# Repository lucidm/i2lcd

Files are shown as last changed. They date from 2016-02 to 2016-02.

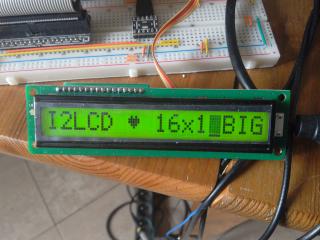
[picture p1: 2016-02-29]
pictures/16x1-big.jpg

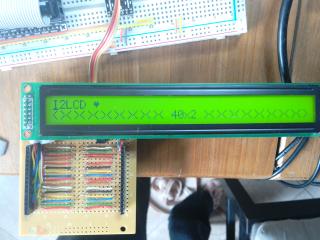
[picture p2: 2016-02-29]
pictures/40x2.jpg

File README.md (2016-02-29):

## I2LCD - I2C HD4470 expansion board with software controlled contrast and backlight

Here's little project of electronic module for ubiquitous Hitachi HD4470 based
alphanumeric displays. Main reason for making the project was to drive the
display using I2C bus. There are many existing I2C extension boards, with most popular
built upon NXP PCF8574 8 bit port expander. This module however, use NXP PCA9535 16 bit expander and
provide few additional functions.

PCB of the module was made in KiCAD 4.0. Generated gerber
files were sent to the PCD manufacturer and after few minor modifications and
few weeks later, PCB of a prototype were sent back. Here are the results.

## What's the difference.

- **Full 8 bit communication with the display**.
  It uses PCA9535 16 bit expander, so we have spare IO ports to
communicate using full 8 bit width words. In popular I2C expansion modules
4 bits are used to drive control lines of the display and 4 other bits are used
as data lines. This module project, was made to provide full 8 bit communication.
No need to send data bytes as two 4 bit chunks although sent as 8 bits of which
4 bits are meaningful and 4 other are just ignored.

- **You can read data from the display**.
  Not all I2C modules provide ability to read from the display. Some of
implementations have hard-wired R/W line assuming user will always write to the
display. Using this module you are able to read data from the module. Attached example
libraries use this feature to read the busy flag of the display. No longer
arbitrary delays in your code, your code waits as long as it is required for the
display to finish.

- **Contrast and backlight intensity are handled programmatically**.
  Another eight IO lines are used for driving control lines of a display and
changing backlight intensity, setting contrast and other functions.
Usually I2C expansion modules use a potentiometer to set contrast of a
display, depending on the module, contrast setting may differ, so you take
a screwdriver and change the pot until the display shows its content with
desired contrast. The module has two electronic potentiometers to set
the contrast and for changing backlight intensity. Where on popular I2C
modules you're able to switch backlight on or off. Potentiometers use simple
Up/Down communication protocol.

- **You can programmatically switch on or off the display power supply**.
Additional line is used to switch the display power on or off. If for some reason
the display should be switched off (to save battery usage for example), you can
do it from your code. However there are some issues regarding this version of
module. Read this Wiki article about known issues and how to get rid of them.

If you like to read more about the module please follow this link:
https://github.com/lucidm/i2lcd/wiki

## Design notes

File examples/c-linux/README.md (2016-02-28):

## I2LCD Userspace C library

Here is I2LCD library written in C for Linux. Library use exsiting I2C device
so the modules for I2C bus should be loaded into kernel prior to use this library.
No external libraries were linked, library use Linux API entirely.

Main directory contains few examples, i2lcd subdirectory contains source code of
the library.

## Examples:

* editlcd - LCD content editor. You can edit content of the display in realtime in
  convenient window. Editor also allow to edit graphical characters and save its
  definiton to C header file.

* lcdbricontest - simple test using brighness and contrast manipulation which shows
  current value of those parameters on the display.

* lcdtest - simple test of the display

## Library - i2lcd subdirectory

* i2lcd.c - main library source file
* i2lcd.h - header for i2lcd.c
* pca9535.c - source of api for PCA9535 chip used by i2lcd.c
* pca9535.h - header file for the above
* pots.c - source of api of the potentiometers used in the module
* pots.h - header for pots.c api

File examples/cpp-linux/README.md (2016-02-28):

## I2LCD Userspace C++ library

Library for I2LCD module written in C++ for Linux. Library use exsiting I2C device
so the modules for I2C bus should be loaded into the kernel prior to use this library.
No external libraries were linked, library use Linux API entirely. Library defines
I2Lcd class with api methods to control the display. Whole definition was i2lcd
namespace enclosed. Only the '<<' operator is defined outside of the namespace,
to provide ability to dump content of the display to ostream object.

Main directory contains few examples and library itself.

## Examples:

* lcdtest - simple test of the display

## The library

* i2lcd.cpp - main library source file, with I2Lcd class API for the display
* i2lcd.h - header for i2lcd.c
* pca9535.cpp - source of PCA9535 class with its API
* pca9535.h - header file for the above
* pots.cpp - source of Potentiometer class and its API
* pots.h - header for pots.cpp api

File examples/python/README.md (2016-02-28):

## I2LCD Userspace Python library

Here is I2LCD library written in Pyhton for Linux. Library is using exsiting I2C device
so the modules for I2C bus should be loaded into kernel prior to use this library.
No external libraries were used, library use Linux API entirely.

Main directory contains few examples, i2lcd subdirectory contains source code of
the library.

## Examples:

* lcdtest - simple test of the display

## Library - i2lcd subdirectory

* i2lcd.py - main library source file
* lcdconst.py - constants used by the library
* pca9535.py - source of api for PCA9535 chip used by i2lcd.py
* pots.py - source of api of the potentiometers used in the module
* lcdstatusflag.py - classes for different method of maintaining status flags
  of the display

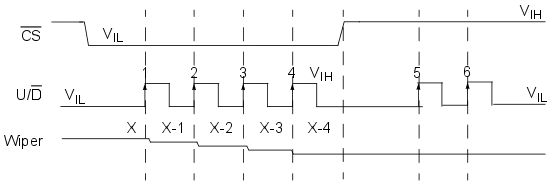
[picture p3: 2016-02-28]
pictures/mcp401x-8.png

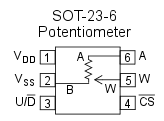
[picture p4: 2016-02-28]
pictures/mcp401x-1.png

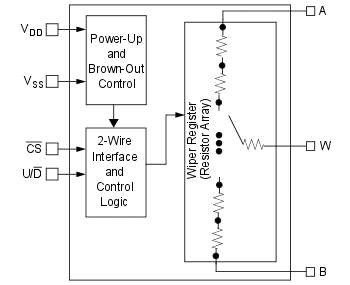
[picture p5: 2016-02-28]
pictures/mcp401x-2.png

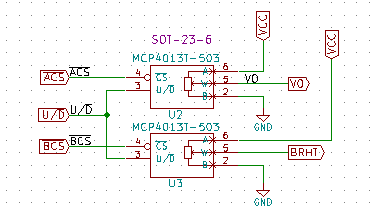
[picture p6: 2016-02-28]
pictures/mcp-connections3.png

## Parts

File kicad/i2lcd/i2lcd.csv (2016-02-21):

Id | Oznaczenie | Obudowa | Ilość | Oznaczenie | Dostawca i numer artykułu
1 | C48,C47,C46,C45,C44,C43,C42,C41,C40,C39,C38,C37,C36,C35,C34,C33,C32,C31,C30,C29,C28,C27,C26,C25,C24,C23,C22,C21,C20,C19,C18,C17,C16,C15,C14,C13,C12,C11,C10,C9,C8,C7,C6,C5,C1,C2,C3,C4 | C_0603 | 48 | 100n
2 | DS12,DS11,DS10,DS9,DS8,DS7,DS6,DS5,DS4,DS3,DS2,DS1 | Pin_Header_Straight_1x16 | 12 | LCD-016N002L
3 | U72,U71,U70,U69,U68,U67,U66,U65,U64,U63,U62,U3 | SOT-23-6 | 12 | MCP4013T-503
4 | U61,U60,U59,U58,U57,U56,U55,U54,U53,U52,U51,U2 | SOT-23-6 | 12 | MCP4013T-503
5 | U50,U49,U48,U47,U46,U45,U44,U43,U42,U41,U40,U39,U38,U37,U36,U35,U34,U33,U32,U31,U30,U29,U5,U4 | SOT-23-5 | 24 | 74AHC1G14
6 | R84,R83,R82,R81,R80,R79,R78,R77,R76,R75,R74,R2 | R_0603 | 12 | 100k
7 | Q24,Q23,Q22,Q21,Q20,Q19,Q18,Q17,Q16,Q15,Q14,Q1 | SOT-23 | 12 | IRLML6244
8 | R73,R72,R71,R70,R69,R68,R67,R66,R65,R64,R63,R4 | R_0603 | 12 | 220k
9 | R62,R61,R60,R59,R58,R57,R56,R55,R54,R53,R52,R40,R39,R38,R37,R36,R35,R34,R33,R32,R31,R30,R29,R28,R27,R26,R25,R24,R23,R22,R21,R20,R19,R18,R17,R16,R15,R14,R13,R12,R11,R10,R9,R8,R3,R5,R6,R7 | R_0603 | 48 | 4.7k
10 | R51,R50,R49,R48,R47,R46,R45,R44,R43,R42,R41,R1 | R_0603 | 12 | 47k
11 | U28,U27,U26,U25,U24,U23,U22,U21,U20,U19,U18,U6 | TSSOP-14_4.4x5mm_Pitch0.65mm | 12 | 74LS21
12 | U17,U16,U15,U14,U13,U12,U11,U10,U9,U8,U7,U1 | TSSOP-24_4.4x7.8mm_Pitch0.65mm | 12 | PCA9535
13 | P24,P23,P22,P21,P20,P19,P18,P17,P16,P15,P14,P1 | Pin_Header_Straight_1x05 | 12 | CONN_01X05
14 | Q13,Q12,Q11,Q10,Q9,Q8,Q7,Q6,Q5,Q4,Q3,Q2 | SOT-23 | 12 | BT2N2222
15 | P13,P12,P11,P10,P9,P8,P7,P6,P5,P4,P3,P2 | SOT-23-6 | 12 | CONN_02X03

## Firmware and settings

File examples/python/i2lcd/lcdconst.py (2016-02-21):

# -*- coding: utf-8 -*-

#Control/Data ports numbers
CPORT = 0
DPORT = 1

#Control port bits meaning
EN = 1
RW = 1 << 1
RS = 1 << 2
IRS = 1 << 3
PWR = 1 << 4
UD = 1 << 5
CCS = 1 << 6
BCS = 1 << 7

#HD4470 instructions
CLEAR_DISPLAY = 1
CURSOR_HOME = 1 << 1
ENTRY_MODE_SET = 1 << 2
DISPLAY_ONOFF = 1 << 3
CURSOR_DISPLAY_SHIFT = 1 << 4
FUNCTION_SET = 1 << 5
SET_CGRAM_ADDRESS = 1 << 6
SET_DDRAM_ADDRESS = 1 << 7

#Values of instructions above
#ENTRY MODE SET
EMS_S = 1		#1 - Shift display
EMS_ID = 1 << 1	#0 - Dec cursor, 1 - inc cursor pos
    
#DISPLAY ON OFF
DOO_B = 1		#1 - Blink ON, 0 - Blink OFF
DOO_C = 1 << 1	#1 - Cursor ON, 0 - Cursor OFF
DOO_D = 1 << 2	#1 - Display ON, 0 - Display OFF
    
    #CURSOR DISPLAY SHIFT
CDS_RL = 1 << 2	#1 - shift right, 0 - shift left
CDS_SC = 1 << 3	#1 - shift display, 0 - move cursor

#FUNCTION SET
FS_F = 1 << 2	#1 - 5x10 dots, 0 - 5x8 dots
FS_N = 1 << 3	#1 - 2 lines, 0 - 1 line
FS_DL = 1 << 4	#1 - 8 bit interface, 0 - 4 bit interface

#BUSY FLAG
BF = 1 << 7		#1 - busy, 0 - can accept instruction

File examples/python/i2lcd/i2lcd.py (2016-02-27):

# -*- coding: utf-8 -*-

from time import sleep
import textwrap
import lcdconst
from pca9535 import PCA9535
from pots import Potentiometer
from statusflag import DelayWaiter, BusyLoop

def _checkPos(function):
    def _f(*args):
	obj = args[0]
	if args[1] >= obj.cols or args[1] < 0:
	    raise ValueError('Column {0} is not between 0-{0}.'.format(args[1], obj.cols - 1))

	if args[2] >= obj.rows or args[2] < 0:
	    raise ValueError('Row {0} is not between 0-{0}.'.format(args[2], obj.rows - 1))

	return function(*args)
    return _f



class I2LCD(object):
    memaddr = {	6  : {1: [0x00], },
                8  : {1: [0x00], 2: [0x40]},
		12 : {4: [0x00, 0x40, 0x0C, 0x4C]},
		16 : {0: [0x00], 1 : [0x00, 0x40], 2 : [0x00, 0x40], 4 : [0x00, 0x40, 0x10, 0x50]},
	        20 : {2 : [0x00, 0x40], 4 : [0x00, 0x40, 0x14, 0x54]},
		24 : {2 : [0x00, 0x40]},
		40 : {2 : [0x00, 0x40]},
	      }

    pottransctable = [0,10,16,21,24,27,29,31,33,35,36,37,39,40,41,42,43,44,44,45,46,47,47,48,49,49,50,50,51,51,52,52,53,53,54,54,55,55,55,56,56,57,57,57,58,58,58,59,59,59,60,60,60,60,61,61,61,62,62,62,62,63,63,63]
    pottransbtable = [0,13,21,27,30,34,36,38,40,42,43,45,46,47,48,48,49,50,51,51,52,52,53,53,54,54,55,55,55,56,56,56,56,57,57,57,58,58,58,58,58,59,59,59,59,59,59,60,60,60,60,60,60,60,60,61,61,61,61,61,61,61,61,61]

    def __init__(self, bus, address, cols, rows):
	self.iface = PCA9535(bus, address)

	if not self.memaddr.has_key(cols):
	    raise NotImplementedError
	if not self.memaddr[cols].has_key(rows):
	    raise NotImplementedError

	self.rowsaddress = self.memaddr[cols][rows]
	self.cols = 8 if rows == 1 else cols
	self.rows = 2 if rows == 1 else rows if rows else 1
	self.column = 0
	self.row = 0
	self.control = 0x00
	self.setControl(self.control, 0)
	self.iface.setPortDir(lcdconst.CPORT, lcdconst.IRS | lcdconst.UD | lcdconst.BCS | lcdconst.CCS)
	self.iface.setPortDir(lcdconst.DPORT, 0x00)
	self.wait = DelayWaiter(self)
	self.iface.setPortOutput(lcdconst.DPORT, 0x00)

	self.cpot = Potentiometer(self.iface, lcdconst.CCS, lcdconst.UD)
	self.bpot = Potentiometer(self.iface, lcdconst.BCS, lcdconst.UD)

	self.control |= self.iface.getPortOutput(lcdconst.CPORT)
	self.setControl(self.control, 1)
	self.commands = {lcdconst.CLEAR_DISPLAY : 0,
			    lcdconst.CURSOR_HOME : 0,
			    lcdconst.ENTRY_MODE_SET : 0,
			    lcdconst.DISPLAY_ONOFF : 0,
			    lcdconst.CURSOR_DISPLAY_SHIFT : 0,
			    lcdconst.FUNCTION_SET : 0,
			    lcdconst.SET_CGRAM_ADDRESS : 0,
			    lcdconst.SET_DDRAM_ADDRESS : 0}
	self.waitflag = 0

    def __del__(self):
	self.power(0)
	self.close()

    def close(self):
	self.setContrast(0x00)
	self.setBacklight(0x00)
	self.setControl(lcdconst.EN | lcdconst.PWR, 0)
	self.iface.setPortDir(lcdconst.CPORT, 0xFF)
	self.iface.setPortDir(lcdconst.DPORT, 0xFF)

    def setControl(self, control, value):
	self.control = (self.control | control) if value else (self.control & ~control)
	self.iface.setPortOutput(lcdconst.CPORT, self.control)

    def setDirection(self, direction):
	self.iface.setPortDir(lcdconst.DPORT, direction)

    def command(self, command, value):
	while (self.waitflag and self.readStatus()[0]):
	    continue
	data = command | value
	self.setControl(lcdconst.RS | lcdconst.RW, 0)
	self.setControl(lcdconst.EN, 1)
	self.iface.setPortOutput(lcdconst.DPORT, data)
	self.setControl(lcdconst.RS | lcdconst.RW | lcdconst.EN, 0)
	self.commands[command] = value

    def readStatus(self):
	self.setControl(lcdconst.RS, 0)
	self.setControl(lcdconst.RW, 1)
	self.setDirection(0xFF)
	self.setControl(lcdconst.EN, 1)
	ret = self.iface.getPortInput(lcdconst.DPORT)
	self.setControl(lcdconst.RS | lcdconst.RW | lcdconst.EN, 0)
	self.setDirection(0x00)
	return (ret & lcdconst.BF, ret & ~lcdconst.BF)

    def writeByte(self, value):
	self.setControl(lcdconst.RS, 1)
	self.setControl(lcdconst.RW, 0)
	self.setControl(lcdconst.EN, 1)
	self.iface.setPortOutput(lcdconst.DPORT, value)
	self.setControl(lcdconst.RS | lcdconst.RW | lcdconst.EN, 0)

    def readBlock(self, l):
	self.setControl(lcdconst.RS, 1)
	self.setControl(lcdconst.RW, 1)
	ret = []
	for b in xrange(l):
	    self.setControl(lcdconst.EN, 1)
	    ret.append(self.iface.getPortInput(lcdconst.DPORT))
	    self.setControl(lcdconst.EN, 0)
	self.setControl(lcdconst.RS | lcdconst.RW | lcdconst.EN, 0)
	return ret

    def writeBlock(self, values):
	self.setControl(lcdconst.RS, 1)
	self.setControl(lcdconst.RW, 0)
	for b in values:
	    self.setControl(lcdconst.EN, 1)
	    self.iface.setPortOutput(lcdconst.DPORT, b)
	    self.setControl(lcdconst.EN, 0)
	self.setControl(lcdconst.RS | lcdconst.RW | lcdconst.EN, 0)

    def readDataByte(self):
	self.setControl(lcdconst.RS, 1)
	self.setControl(lcdconst.RW, 1)
	self.setDirection(0xFF)
	self.setControl(lcdconst.EN, 1)
	ret = self.iface.getPortInput(lcdconst.DPORT)
	self.setControl(lcdconst.RS | lcdconst.RW | lcdconst.EN, 0)
	self.setDirection(0x00)
	return ret

    def readRow(self, row):
	self.command(lcdconst.SET_DDRAM_ADDRESS, self.rowsaddress[row])
	self.setControl(lcdconst.RS, 1)
	self.setControl(lcdconst.RW, 1)
	self.setDirection(0xFF)
	ret = ""
	for i in range(self.cols):
	    self.setControl(lcdconst.EN, 1)
	    ret += chr(self.iface.getPortInput(lcdconst.DPORT))
	    self.setControl(lcdconst.EN, 0)
	self.setControl(lcdconst.RS | lcdconst.RW, 0)
	self.setDirection(0x00)
	self.setCursor(self.column, self.row)
	return ret

    @_checkPos
    def setCursor(self, column, row):
	row %= self.rows
	column %= self.cols
	self.column = column
	self.row = row
	address = self.rowsaddress[row]+column
	self.command(lcdconst.SET_DDRAM_ADDRESS, address)

    def clear(self):
	self.command(lcdconst.CLEAR_DISPLAY, 0x00)
	self.column = 0
	self.row = 0

    def home(self):
	self.command(lcdconst.CURSOR_HOME, 0x00)
	self.column = 0
	self.row = 0

    def setGC(self, number, definition):
	self.command(lcdconst.SET_CGRAM_ADDRESS, ((number & 0x07) << 3))
	self.writeBlock(definition)

    def fprint(self, string):
	column = self.column
	row = self.row

	for i, line in enumerate(string.rstrip().split('\n')):
	    self.command(lcdconst.SET_DDRAM_ADDRESS, self.rowsaddress[row]+column)
	    wrap = textwrap.wrap(line, self.cols if column == 0 else self.cols - column)
	    for j, txt in enumerate(wrap):
		self.writeBlock([ord(c) for c in txt])
		column += len(txt)
		if column >= self.cols:
		    column = 0
		    row = (row + 1) % self.rows
		    self.command(lcdconst.SET_DDRAM_ADDRESS, self.rowsaddress[row]+column)
	    if i > 0:
		column = 0
		row = (row + 1) % self.rows
	self.column = column % self.cols
	self.row = row

    def init(self):
	if self.rows == 1:
	    fn = 0
	else:
	    fn = lcdconst.FS_N
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
